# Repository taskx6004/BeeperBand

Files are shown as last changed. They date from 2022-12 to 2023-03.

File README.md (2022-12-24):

# BeeperBand

The BeeperBand is an open hardware project to build a minimalist wrist band to notify smartphone message notification with haptic, RGB lights, and interact with physical buttons via BLE connection.

Current prototype intentionally not fitting any display, there are only 3 RGB LEDs, for visual indications. A Linear Haptic Driver can notify user with patterned vibration with minimum audible noise, for non-intrusive usage in various social occasions.

The hardware design is a basically a re-layout PCB of a Adafruit nRF52 Express, to minimize initial firmware development efforts. It also has more sophisticated charger, peripherals required by project specs, and various design decisions for power saving and MCU IO voltage level translations, to utilize software configurable voltage features of nRF52 integrated power converters.

## System Design

nRF52840 is a 2.4GHz RFIC with integrated power converters and flexible IO mapping, with USB2.0 full speed PHY, but has no DFU rom(will brake when no proper firmware present). It can be powered directly with USB host or Li-ion battery, with two stage convert, or single stage convert (skipping first high voltage conversion); two stage conversion could both choose between integrated LDO or buck converter, while buck converter require extra inductors and capacitors to be functional.

To maximize battery life, the BeeperBand implemented two stage buck converter design, all peripheral I/Os have dedicated level translation, and core of nRF52840 works on default 1.8v.

Current stage there’s no functional firmware for BeeperBand hardware (v0.41), all testing is done with Adafruit Feather nRF52840 express bootloader and accompanying BSP and Arduino.

## Peripherals

- 6 GPIO buttons, low-active (enabled when connected to GND)
- 3 x RGB LEDs, SW2812 serial protocol, daisy chained
  - powered by dedicated 3.3V buck converter, with EN pin
  - buck converter is powered by battery
- 1x Linear Haptic Driver
  - dedicated level transfer chip for I2C and GPIO
  - powered by battery, wide voltage range tolerate by level translation
- All unused IO fanned out by 30pin B2B connector
  - with battery output pins
  - 20 IO pins
- 2 LEDs, inherent from Adafruit nRF52840 Feather Express Design
  - RED for Arduino serial activity
  - BLUE for BLE connection activity
  - testing purpose, so the brightness is set to very low (1k resistor on 1.8V IO)

## Charger Circuit

Charger chip is BQ25619 from Texas Instrument with QFN footprint. A WLCSP footprint version is available with part# BQ25618. If PCB size requires further miniaturization, charger and MCU chip can  both replaced with software compatible WLCSP (0.4mm pitch BGA) footprint version.

Like many other BQ chargers from TI, it has a register map for extensive internal controls. But preliminary charging functions does no require MCU control presents. The I/O pins connected to the charger are unused in Feather Express design, so application developer can ignore its presents. To reach 4.2V charge voltage (default 4.1V), and charging current control, a driver firmware is required, and it will work with no intervention to application programs. The power source transition between charging and battery is also seamless, with no program control needed.

BQ chip has 4 power terminals, a little back ground may be helpful in first encounter.

- USB input (VBUS)
  - charge power input
- USB output (PMID)
  - if USB power output as a USB host is required, BQ chip works can work in boost mode to deliver 5V output from battery voltage.
- Battery output (VSYS)
  - Li-ion battery have a minimum voltage required to prevent over discharge, this output will shutdown output to protect battery. If system is overheat, or charge voltage is over-voltage, BQ will also disconnect battery connection.
- Battery input (BAT)
  - This is the dedicated battery connection node. BQ chip has no discharge meter to implement an accurate gas gauge function, but a battery voltage monitor circuit exist in system, to save power this circuit could be shutdown to prevent power leak.

## Testing procedure

PCBA is hand built, this is a long process and require lots of craftsmanship. The SWD port used for upload firmware is not a standard pulg but four small soldering pads, to save space. Fresh nRF52 chip has no per-programmed boot-loader, nor the USB has a hardware DFU mode to boot is from desktop operating system.  To test hardware functionalities, the Adafruit Feather nRF52 Express bootloader is flashed.

Testing procedures are done with Arduino sketches, requires user to upload them separately for each function:

- Buttons
  - not fully implemented due to default Ardruino BSP include only one PIN\_BUTTON(7)
- RGB leds
  - PIN\_NEOPIXEL (8))
- Haptic
  - Requires Adafruit\_DRV2605.h
  - Change writeRegister8(DRV2605\_REG\_OVERDRIVE, 1);
  - call “use\_LRA() in setup()

Currently charger driver is not implemented, but charger I2C communication could be verified.

## Firmware Development

Due to lack of BLE communication software nor data model design, a serial based BLE protocol to manipulate system peripheral called Firmata is recommended to make use cases mock up. During this testing phase, there’s no sophisticated radio power control method could be implemented. This mock up communication firmware will have significant more power consumption than a production firmware, due to communication protocol overhead and onboard program overhead.

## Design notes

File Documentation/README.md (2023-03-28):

# **BeeperBand Firmware Dev 101**

Assuming you are a proficient C Kernel developer, or a CPP application programmer, this is the first time to work with an embedded system, this document will guide you through the first adventure to make BeeperBand blinking as you wish.

## **Porting BeeperBand as a new Arduino hardware**

Before your program could be uploaded (old fashioned embedded programmer would say, it’s downloaded) to the FLASH resides inside MCU, you will need a BSP in your IDE to invoke hardware specific commands with generic function call naming conventions, such as LEDPIN or PULLUP etc, so you don’t have to search through MCU datasheet’s register table or vendor’s library source code; And another thing required is the bootloader could use USB to talk with IDE’s firmware flashing program, or you will have to use an extra USB dongle generically called “JTAG”, to flash your binary file with specific location to boot the MCU.

This is why BeeperBand schemaitc has a weird pin mapping

CleanShot 2023-03-24 at 08 53 42@2x

This mapping is how the BSP, specifically, nRF52840 chip’s Arduino port, from “Adafruit Feather nRF52840 Express” dongle, has done. BeeperBand’s RGB LED is connected to NEOPIX pin is connected to P0.16 pin, existing program works with NEOPIX pin will work with BeeperBand as well, all you need to do is refer to [https://learn.adafruit.com/introducing-the-adafruit-nrf52840-feather/arduino-bsp-setup](https://learn.adafruit.com/introducing-the-adafruit-nrf52840-feather/arduino-bsp-setup), pretending BeeperBand is a Feather board.

But BeeperBand has extended this BSP, you will need to figure out how BSP package is resided in your specific OS (windows, linux, MacOS), and try to update vanilla BSP project to make new definitions for BeeperBand hardware work, e.g. P1.07, to enable or disable the NEOPIX LED’s power converter, to save some few milliamp current, where this pin is not fanned out in Adafruit Feather nRF52840 Express. BSP project is on GitHub: [https://github.com/adafruit/Adafruit_nRF52_Arduino](https://github.com/adafruit/Adafruit_nRF52_Arduino), inside the “variants” folder, create a new folder for BeeperBand, and copy a sibling folder as a template.

Note before uploading new program to BeeperBand:

- has your new board entry appear in your Arduino IDE?
- New firmware compiled with your BSP project indeed working? Try toggle some newly defined pins
- HS and LS pins are same in function, but LS pins’ traces inside chip are located near wireless part, use them for bus data will degrade it’s communication performance, so use LS pins for low speed IO commands such as chip enable etc.
- All pins on nrf52840 could be used for specific bus functions, e.g. I2C or SPI. AIN_pins are analog input pins, not usually used for these purposes.

There’s another project you will need to take care of, it’s the Bootloader: [https://github.com/adafruit/Adafruit_nRF52_Bootloader](https://github.com/adafruit/Adafruit_nRF52_Bootloader)

## **Update Bootloader**

This is a “miniaturized” BSP project, resides in FLASH, could be invoked by pressing RESET button during power on the BeeperBand, or automatically running when no program exists in your BeeperBand. The mapping file located in Adafruit_nRF52_Bootloader/src/**boards**/ folder.

Be careful if this program not running properly, your device is bricked. Brick means there’s no booting firmware program exists to bring up basic functions, e.g. USB device to communicate with Arduino. You will have to connect SWD port with a SWD download device, with vendor’s flash program.

Refer to [flashing guide.odt] to un-brick.

Bootloader’s job is to get user program running (aka, the binary BSP built with your *.ino in Arduino IDE), unless there’s no working user program or user choose to boot to Bootloader. Once BSP program is loaded, there’s no effect what Bootloader has defined, so if your BSP and Bootloader project have different hardware mappings, they will not conflict each other.

## **BeeperBand’s firmware develop goals**

After you can work with BSP and Bootloader project properly, you can begin reading datasheets of each functional component try to build “device driver”. Arduino IDE has its way to organize your driver project from BSP project, and it’s also OS dependent. You are on your own to make this work again, and Adafruit’s tutorial again is a good starting point.

A list of onboard devices required for new drivers:

- Haptic motor, existing driver is incomplete, and some modifications are required to get most power output (in README.md)
- 3x RGB LED array, requires modification of BSP to get the chain length right.
- Battery Charger, will need to define charging current and temperature protection custom criteria
- MCU’s ADC setup for proper battery voltage reading
- All power enable/disable GPIOs for power saving

Then you are ready for BLE development, this is beyond this document.

EOF.

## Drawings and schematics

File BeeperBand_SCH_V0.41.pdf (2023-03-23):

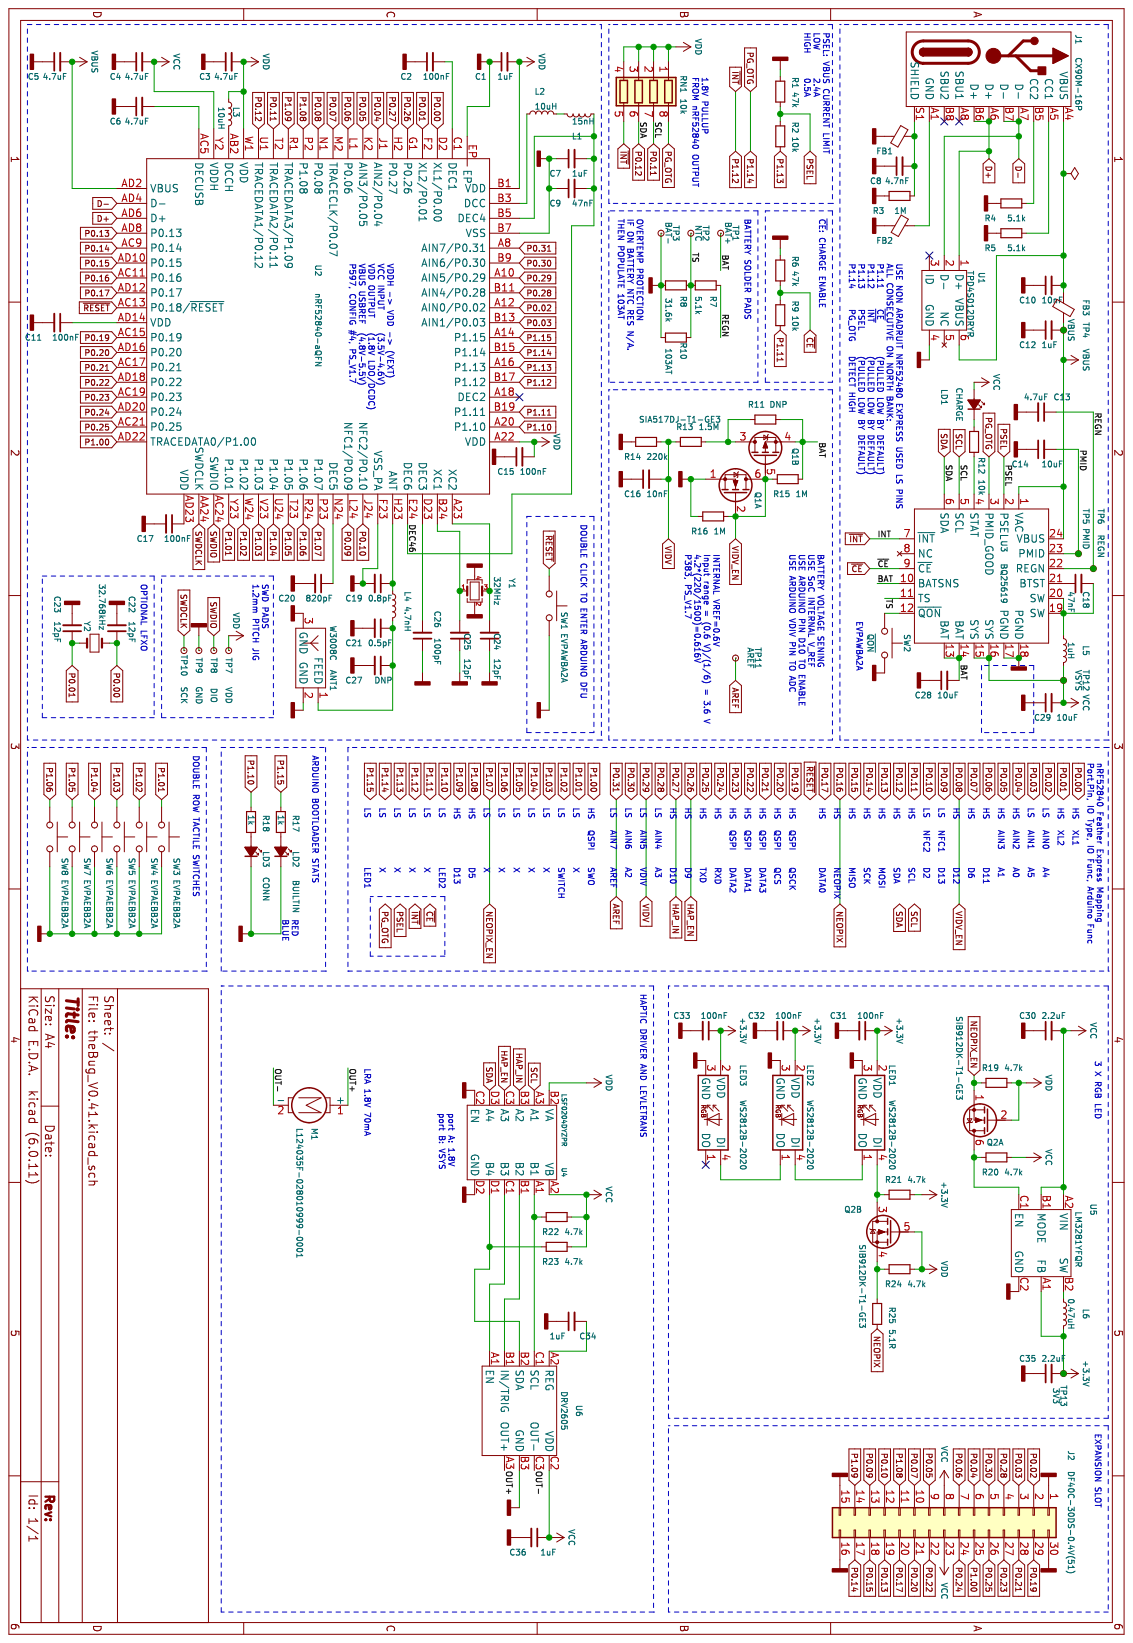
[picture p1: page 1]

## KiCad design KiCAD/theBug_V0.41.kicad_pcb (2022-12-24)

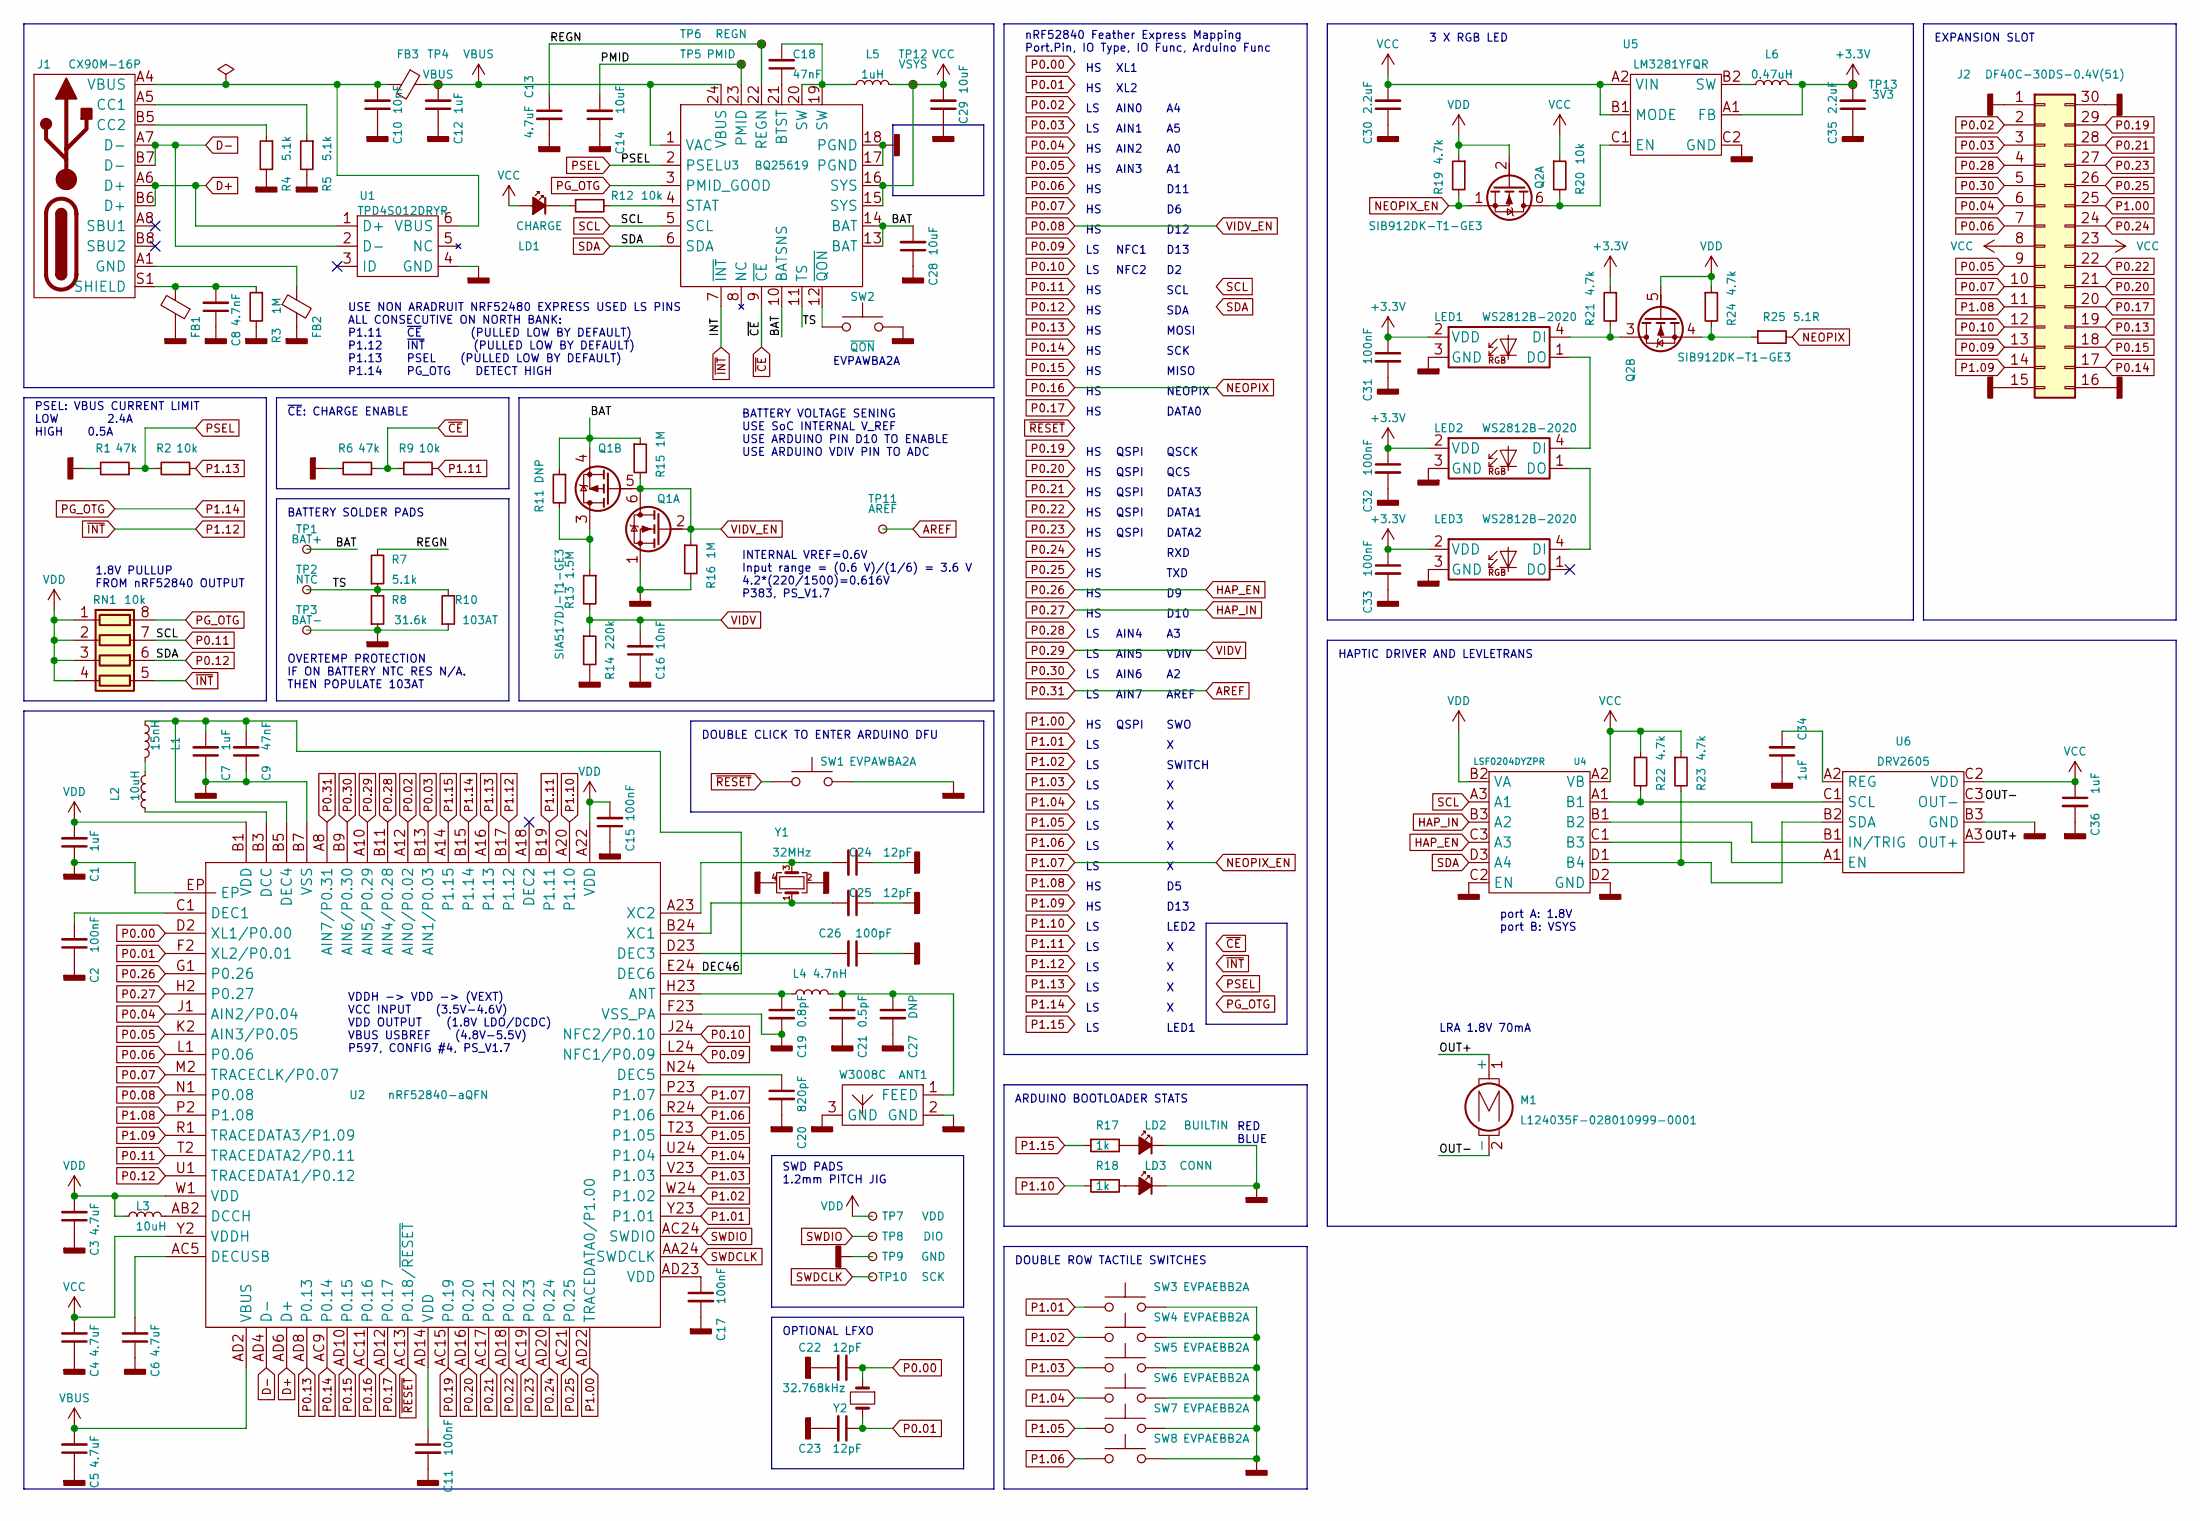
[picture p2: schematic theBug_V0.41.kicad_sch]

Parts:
ANT1: W3008C
C1, C7, C12, C34, C36: 1uF; C_0201
C2, C11, C15, C17, C31, C32, C33: 100nF; C_0201
C3, C4, C5, C6, C13: 4.7uF; C_0402_1005Metric
C8: 4.7nF; C_0201
C9, C18: 47nF; C_0201
C10, C16: 10nF; C_0201
C14, C28, C29: 10uF; C_0402_1005Metric
C19: 0.8pF; C_0201
C20: 820pF; C_0201
C21: 0.5pF; C_0201
C22, C23, C24, C25: 12pF; C_0201
C26: 100pF; C_0201
C27: DNP; C_0201
C30, C35: 2.2uF; C_0201
FB1, FB2, FB3: BLM15EX121SN1D; L_0402_1005Metric
J1: CX90M-16P; HRS_CX90M-16P
J2: DF40C-30DS-0.4V(51); DF40C(2.0)-30DS-0.4V(51)
L1: 15nH; L_0201_0603Metric
L2, L3: 10uH; L_0603_1608Metric
L4: 4.7nH; L_0201_0603Metric
L5: 1uH; WIP252010P-1R0ML
L6: 0.47uH; L_0402_1005Metric
LD1: CHARGE; LED_0402
LD2: BUILTIN; LED_0402
LD3: CONN; LED_0402
LED1, LED2, LED3: WS2812B-2020
M1: L124035F-028010999-0001; LL-3-J-27150
Q1: SIA517DJ-T1-GE3; Vishay_PowerPAK_SC70-6L_Dual
Q2: SIB912DK-T1-GE3; Vishay_PowerPAK_SC75-6L_Dual
R1, R6: 47k; R_0201
R2, R9, R12, R20: 10k; R_0201
R3: 1M; R_0402_1005Metric
R4, R5, R7: 5.1k; R_0201
R8: 31.6k; R_0201
R10: 103AT; R_0201
R11: DNP; R_0201
R13: 1.5M; R_0201
R14: 220k; R_0201
R15, R16: 1M; R_0201
R17, R18: 1k; R_0201
R19, R21, R22, R23, R24: 4.7k; R_0201
R25: 5.1R; R_0201
RN1: 10k; R_Array_Convex_4x0402
SW1: EVPAWBA2A
SW2: ~{QON}; EVPAWBA2A
SW3, SW4, SW5, SW6, SW7, SW8: EVPAEBB2A
TP1: BAT+; TestPoint_Pad_D0.6mm
TP2: NTC; TestPoint_Pad_D0.6mm
TP3: BAT-; TestPoint_Pad_D0.6mm
TP4: VBUS; TestPoint_Pad_D0.6mm
TP5: PMID; TestPoint_Pad_D0.6mm
TP6: REGN; TestPoint_Pad_D0.6mm
TP7: VDD; TestPoint_Pad_D0.6mm
TP8: DIO; TestPoint_Pad_D0.6mm
TP9: GND; TestPoint_Pad_D0.6mm
TP10: SCK; TestPoint_Pad_D0.6mm
TP11: AREF; TestPoint_Pad_D0.6mm
TP12: VSYS; TestPoint_Pad_D0.6mm
TP13: 3V3; TestPoint_Pad_D0.6mm
U1: TPD4S012DRYR
U2: nRF52840-aQFN; Nordic_AQFN-73-1EP_7x7mm_P0.5mm
U3: BQ25619
U4: LSF0204DYZPR
U5: LM3281YFQR
U6: DRV2605; DRV2605YZFR
Y1: 32MHz; Crystal_SMD_2016-4Pin_2.0x1.6mm
Y2: 32.768kHz; Crystal_SMD_2012-2Pin_2.0x1.2mm

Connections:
+3.3V: C31.1, C32.1, C33.1, C35.2, L6.2, LED1.2 (VDD), LED2.2 (VDD), LED3.2 (VDD), R21.1, TP13.1, U5.A1 (FB)
/BAT: C28.2, Q1.4, R11.1, R15.1, TP1.1, U3.10 (BATSNS), U3.13 (BAT), U3.14 (BAT)
/DEC46: C7.2, C9.2, L1.2, U2.B5 (DEC4), U2.E24 (DEC6)
/OUT+: M1.1 (+), U6.A3 (OUT+)
/OUT-: M1.2 (-), U6.C3 (OUT-)
/PMID: C14.2, TP5.1, U3.23 (PMID)
/REGN: C13.1, R7.2, TP6.1, U3.22 (REGN)
/TS: R7.1, R8.2, R10.2, TP2.1, U3.11 (TS)
AREF: TP11.1, U2.A8 (AIN7/P0.31)
D+: J1.A6 (D+), J1.B6 (D+), U1.1 (D+), U2.AD6 (D+)
D-: J1.A7 (D-), J1.B7 (D-), U1.2 (D-), U2.AD4 (D-)
GND: ANT1.2 (GND), ANT1.3 (GND), C1.1, C2.1, C3.1, C4.1, C5.1, C6.1, C7.1, C8.1, C9.1, C10.1, C11.2, C12.1, C13.2, C14.1, C15.1, C16.1, C17.2, C19.2, C20.2, C21.2, C22.2, C23.2, C24.1, C25.1, C26.1, C27.2, C28.1, C29.1, C30.1, C31.2, C32.2, C33.2, C34.1, C35.1, C36.2, FB1.1, FB2.2, J2.1, J2.15, J2.16, J2.30, LD2.1 (K), LD3.1 (K), LED1.3 (GND), LED2.3 (GND), LED3.3 (GND), Q1.1, R1.2, R3.2, R4.2, R5.2, R6.2, R8.1, R10.1, R14.2, R16.2, SW1.1, SW2.1, SW3.2, SW4.2, SW5.2, SW6.2, SW7.2, SW8.2, TP3.1, TP9.1, U1.4 (GND), U2.B7 (VSS), U2.EP, U2.F23 (VSS_PA), U3.17 (PGND), U3.18 (PGND), U3.25 (GND), U4.C2 (EN), U4.D2 (GND), U5.C2 (GND), U6.B3 (GND), Y1.2, Y1.4
HAP_EN: U2.G1 (P0.26), U4.C3 (A3)
HAP_IN: U2.H2 (P0.27), U4.B3 (A2)
NEOPIX: R25.2, U2.AC11 (P0.16)
NEOPIX_EN: Q2.1, R19.2, U2.P23 (P1.07)
unnamed: ANT1.1 (FEED), C21.1, C27.1, L4.2
unnamed: C2.2, U2.C1 (DEC1)
unnamed: C6.2, U2.AC5 (DECUSB)
unnamed: C8.2, FB1.2, J1.S1 (SHIELD), R3.1
unnamed: C10.2, FB3.2, J1.A4 (VBUS), J1.A9 (VBUS), J1.B4 (VBUS), J1.B9 (VBUS), U1.6 (VBUS)
unnamed: C11.1, U2.AD14 (VDD)
unnamed: C17.1, U2.AD23 (VDD)
unnamed: C18.1, U3.21 (BTST)
unnamed: C18.2, L5.1, U3.19 (SW), U3.20 (SW)
unnamed: C19.1, L4.1, U2.H23 (ANT)
unnamed: C20.1, U2.N24 (DEC5)
unnamed: C24.2, U2.A23 (XC2), Y1.3
unnamed: C25.2, U2.B24 (XC1), Y1.1
unnamed: C26.2, U2.D23 (DEC3)
unnamed: C34.2, U6.A2 (REG)
unnamed: FB2.1, J1.A1 (GND), J1.A12 (GND), J1.B1 (GND), J1.B12 (GND)
unnamed: J1.A5 (CC1), R5.1
unnamed: J1.B5 (CC2), R4.1
unnamed: L1.1, L2.2
unnamed: L2.1, U2.B3 (DCC)
unnamed: L3.2, U2.AB2 (DCCH)
unnamed: L6.1, U5.B2 (SW)
unnamed: LD1.1 (K), R12.1
unnamed: LD2.2 (A), R17.2
unnamed: LD3.2 (A), R18.2
unnamed: LED1.1 (DO), LED2.4 (DI)
unnamed: LED1.4 (DI), Q2.3, R21.2
unnamed: LED2.1 (DO), LED3.4 (DI)
unnamed: Q1.3, R11.2, R13.1
unnamed: Q2.4, R24.2, R25.1
unnamed: Q2.6, R20.2, U5.C1 (EN)
unnamed: R12.2, U3.4 (STAT)
unnamed: R22.2, U4.A1 (B1), U6.C1 (SCL)
unnamed: R23.2, U4.D1 (B4), U6.B2 (SDA)
unnamed: SW2.2, U3.12 (~QON)
unnamed: U4.B1 (B2), U6.B1 (IN/TRIG)
unnamed: U4.C1 (B3), U6.A1 (EN)
P0.00: C22.1, U2.D2 (XL1/P0.00), Y2.1
P0.01: C23.1, U2.F2 (XL2/P0.01), Y2.2
P0.02: J2.2, U2.A12 (AIN0/P0.02)
P0.03: J2.3, U2.B13 (AIN1/P0.03)
P0.04: J2.6, U2.J1 (AIN2/P0.04)
P0.05: J2.9, U2.K2 (AIN3/P0.05)
P0.06: J2.7, U2.L1 (P0.06)
P0.07: J2.10, U2.M2 (TRACECLK/P0.07)
P0.08: Q1.2, Q1.5, Q1.6, R15.2, R16.1, U2.N1 (P0.08)
P0.09: J2.13, U2.L24 (NFC1/P0.09)
P0.10: J2.12, U2.J24 (NFC2/P0.10)
P0.11: RN1.7 (R2.2), U2.T2 (TRACEDATA2/P0.11), U3.5 (SCL), U4.A3 (A1)
P0.12: RN1.6 (R3.2), U2.U1 (TRACEDATA1/P0.12), U3.6 (SDA), U4.D3 (A4)
P0.13: J2.19, U2.AD8 (P0.13)
P0.14: J2.17, U2.AC9 (P0.14)
P0.15: J2.18, U2.AD10 (P0.15)
P0.17: J2.20, U2.AD12 (P0.17)
P0.19: J2.29, U2.AC15 (P0.19)
P0.20: J2.21, U2.AD16 (P0.20)
P0.21: J2.28, U2.AC17 (P0.21)
P0.22: J2.22, U2.AD18 (P0.22)
P0.23: J2.27, U2.AC19 (P0.23)
P0.24: J2.24, U2.AD20 (P0.24)
P0.25: J2.26, U2.AC21 (P0.25)
P0.28: J2.4, U2.B11 (AIN4/P0.28)
P0.29: C16.2, R13.2, R14.1, U2.A10 (AIN5/P0.29)
P0.30: J2.5, U2.B9 (AIN6/P0.30)
P1.00: J2.25, U2.AD22 (TRACEDATA0/P1.00)
P1.01: SW3.1, U2.Y23 (P1.01)
P1.02: SW4.1, U2.W24 (P1.02)
P1.03: SW5.1, U2.V23 (P1.03)
P1.04: SW6.1, U2.U24 (P1.04)
P1.05: SW7.1, U2.T23 (P1.05)
P1.06: SW8.1, U2.R24 (P1.06)
P1.08: J2.11, U2.P2 (P1.08)
P1.09: J2.14, U2.R1 (TRACEDATA3/P1.09)
P1.10: R18.1, U2.A20 (P1.10)
P1.11: R9.1, U2.B19 (P1.11)
P1.12: RN1.5 (R4.2), U2.B17 (P1.12), U3.7 (~INT)
P1.13: R2.1, U2.A16 (P1.13)
P1.14: RN1.8 (R1.2), U2.B15 (P1.14), U3.3 (PMID_GOOD)
P1.15: R17.1, U2.A14 (P1.15)
PSEL: R1.1, R2.2, U3.2 (PSEL)
SWDCLK: TP10.1, U2.AA24 (SWDCLK)
SWDIO: TP8.1, U2.AC24 (SWDIO)
VBUS: C5.2, C12.2, FB3.1, TP4.1, U2.AD2 (VBUS), U3.1 (VAC), U3.24 (VBUS)
VCC: C4.2, C29.2, C30.2, C36.1, J2.8, J2.23, L5.2, LD1.2 (A), R20.1, R22.1, R23.1, TP12.1, U2.Y2 (VDDH), U3.15 (SYS), U3.16 (SYS), U4.A2 (VB), U5.A2 (VIN), U5.B1 (MODE), U6.C2 (VDD)
VDD: C1.2, C3.2, C15.2, L3.1, Q2.2, Q2.5, R19.1, R24.1, RN1.1 (R1.1), RN1.2 (R2.1), RN1.3 (R3.1), RN1.4 (R4.1), TP7.1, U2.A22 (VDD), U2.B1 (VDD), U2.W1 (VDD), U4.B2 (VA)
~CE: R6.1, R9.2, U3.9 (~CE)
~RESET: SW1.2, U2.AC13 (P0.18/~RESET)

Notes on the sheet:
USE NON ARADRUIT NRF52480 EXPRESS USED LS PINS ALL CONSECUTIVE ON NORTH BANK: P1.11 ~{CE} (PULLED LOW BY DEFAULT) P1.12 ~{INT} (PULLED LOW BY DEFAULT) P1.13 PSEL (PULLED LOW BY DEFAULT) P1.14 PG_OTG DETECT HIGH
HAPTIC DRIVER AND LEVLETRANS
DATA1
QCS
LRA 1.8V 70mA
QSPI
DATA3
DATA2
D13
OPTIONAL LFXO
NEOPIX
ARDUINO BOOTLOADER STATS
MOSI
INTERNAL VREF=0.6V Input range = (0.6 V)/(1/6) = 3.6 V 4.2*(220/1500)=0.616V P383, PS_V1.7
nRF52840 Feather Express Mapping Port.Pin, IO Type, IO Func, Arduino Func
LED1
SWITCH
XL1
TXD
AIN6
EVPAWBA2A
AIN0
AIN3
PSEL: VBUS CURRENT LIMIT LOW 2.4A HIGH 0.5A
DOUBLE CLICK TO ENTER ARDUINO DFU
NFC1
DOUBLE ROW TACTILE SWITCHES
1.8V PULLUP FROM nRF52840 OUTPUT
AIN1
QSCK
DATA0
~{CE}: CHARGE ENABLE
VDDH -> VDD -> (VEXT) VCC INPUT (3.5V-4.6V) VDD OUTPUT (1.8V LDO/DCDC) VBUS USBREF (4.8V-5.5V) P597, CONFIG #4, PS_V1.7
RXD
AIN5
AREF
D11
AIN7
BATTERY SOLDER PADS
AIN4

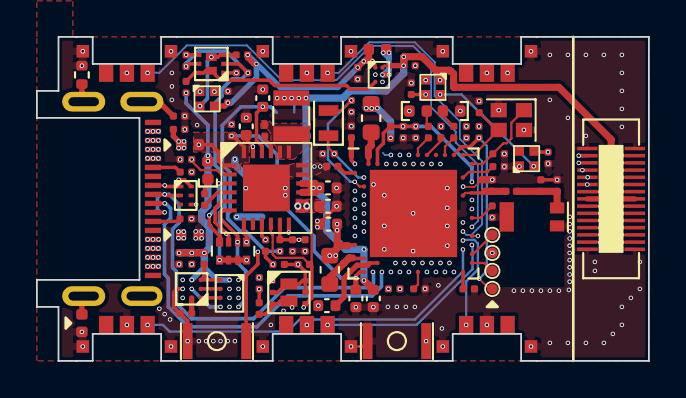
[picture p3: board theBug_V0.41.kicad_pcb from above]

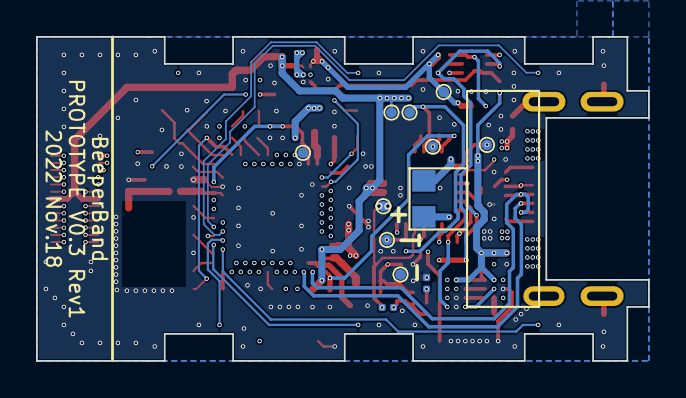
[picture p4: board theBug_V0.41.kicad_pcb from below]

Board: 4 copper layers, 34.0 x 18.0 mm, 112 parts (12 on the bottom side), 103 nets.

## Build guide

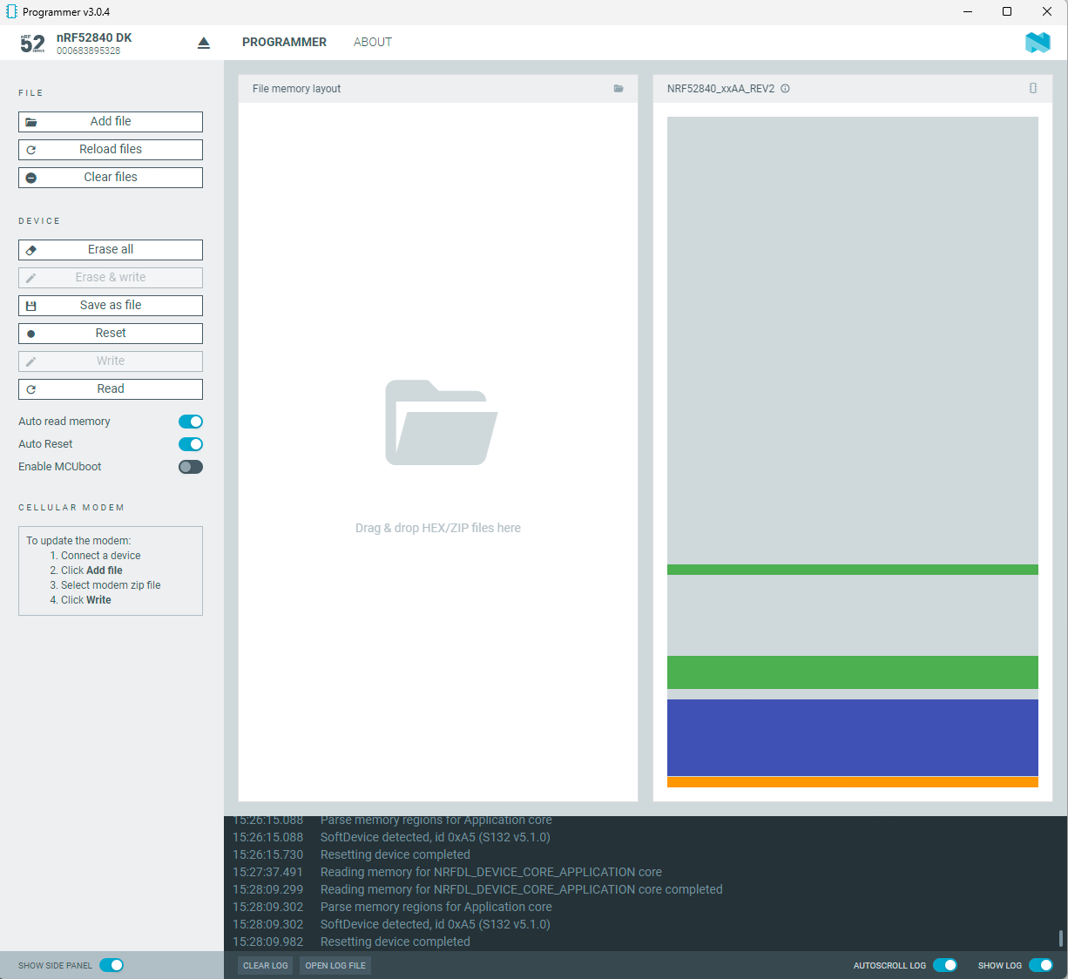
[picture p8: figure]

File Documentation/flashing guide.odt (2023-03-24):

Note before development begins

In some cases, the bootloader onboard gets corrupted, the symptom is Arduino IDE could not write new sketch by USB, or new written sketch could not take effect. This might caused by the process of UF2 firmware gets interrupted somehow, right after uploading, during populating the new sketch into FLASH, but it’s hard to reproduce the process and the exact cause is unknown.

To unbrick the board, re-flash the bootloader is required, an SWD interface dongle is required to do this. The connection of SWD interface needs only two signal wires, SWDIO and SWDCLK, but to successfully talk to SWD interface, VDD from Target is also required, for SWD to detect Target connection (VDD).

Why choose this board

PCA10056 (nRF52840 Development Kit) is the official DK from Nordic Semi, comes with all IOs fanned out, and comes with a J-link Debugger (SWD). nRF52840 has an integrated USB port, which could run directly on USB 5V supply. With 1MB flash and 256KB RAM, to run Arduino code without concerns.

The onboard SWD debugger on nRF52840 Development Kit can also be used to debug external nRF devices, it has sophisticated circuit design to protect your testing target and itself, and this process is automatic. Since DK board already has a nRF52840 onboard, to make sure you have external target connected is being flashed rather than the onboard one, unfortunately there’s no hard switch, it has to be relied on its automatic switch. But after flashing, re-reading FLASH content mapping is possible. To make sure you have flashed the right chip, leaving onboard MCU FLASH blank is a good practice.

Arduino Board Port

Develop firmware on nRF52840 has many ways, official SDK has a steep learning curve and have many version numbers, but running Arduino is also possible, it has been done by Adafruit.

There’re two parts of work to run Arduino, one part is the compiler and BSP files resides in Arduino IDE, the other part is the bootloader on nRF5 chip. Corresponding github links:

(https://github.com/adafruit/Adafruit_nRF52_Arduino)

- https://github.com/adafruit/Adafruit_nRF52_Arduino
- https://github.com/adafruit/Adafruit_nRF52_Bootloader

Documents from these repos are good starting point, just copy and update some board files have successfully tested the Hat hardware, and fully functional.

One last thing about flashing bootloader on a blank nrf52840 chip, or just rewrite/update over existed bootloader, the Bug board needs to be connected with both USB (from battery power source, no host USB), and SWD cable to nRF52840 DK board on upper left P19 socket. DK board need to connected to a PC with nRF Connect for Desktop → Programmer application, and restart DK board by sliding ON/OFF switch on down left corner, to make sure external SWD target is connected. Quick summary:

1. Install nRF Connect for Desktop, install Programmer inside the Desktop app
2. Connect DK board then choose board, make sure it works
3. Connect the Bug SWD to DK board, USB to a power only source, reboot DK board (switch)
4. Re-choose the target from Programmer app, choose bootloader file, flash.
5. Re-read target flash content by removing (hot unplug the Hat’s SWD cable) ensure flashed.

Fig1. choose and install programmer to flash the bootloader)

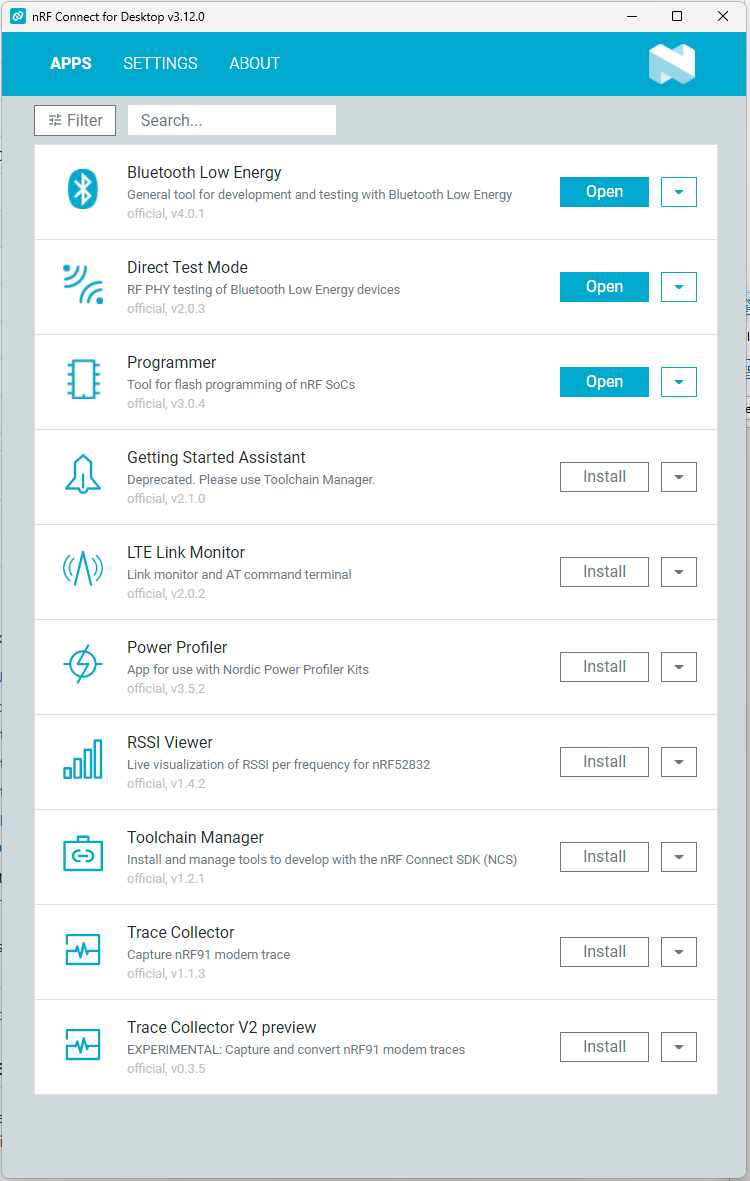
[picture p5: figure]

Fig2. A. Choose device on upper left corner, B. Choose bootloader .HEX file then click Erase & Write

Fig3. Read FLASH content mapping to make sure flashed the right nRF52840 chip.

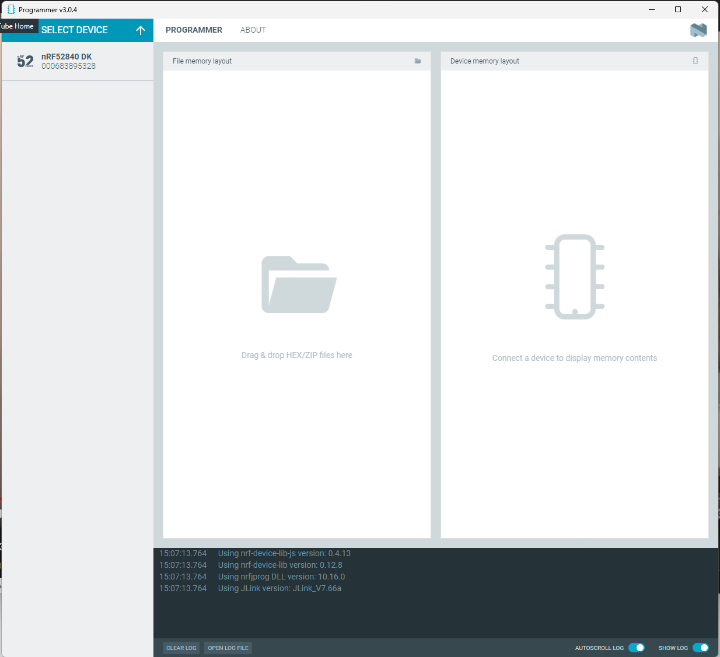
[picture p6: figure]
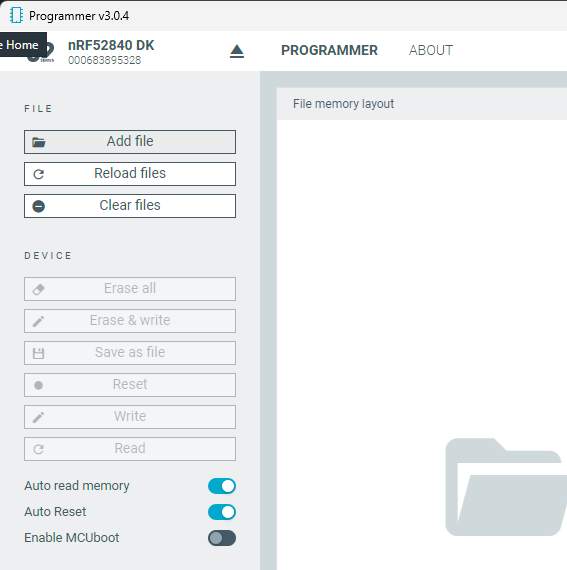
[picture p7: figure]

Fig1: When Programmer app is installed the button turns blue.

Fig2: Left column and eject button to choose SWD device interface.

Fig3: Hex file mapping address vs FLASH content mapping address (no file loaded in picture, if FLASH is blank, mapping table will be all grey)
